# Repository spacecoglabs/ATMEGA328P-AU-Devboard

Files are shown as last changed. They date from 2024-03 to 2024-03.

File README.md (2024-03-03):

# ATMEGA328P-AU-Devboard
A simple KiCADv6 design for a ATMEGA328P-AU Development Board

## Overview 
This repository contains a simple KiCADv6 design for a ATMEGA328P-AU development board. All pins are broken out to headers for prototyping use, with a few exceptions. This design includes an external 16MHz oscillator, power indicator LED, and user controllable LED. The form factor of the board was designed to be as small as possible, without compromising usability. Power can be supplied through the screw terminal, or directly through the various 5V and GND pins.

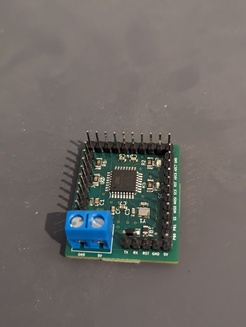
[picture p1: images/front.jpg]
front

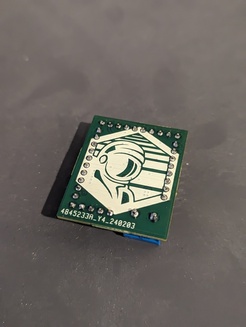
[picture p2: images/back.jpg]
back


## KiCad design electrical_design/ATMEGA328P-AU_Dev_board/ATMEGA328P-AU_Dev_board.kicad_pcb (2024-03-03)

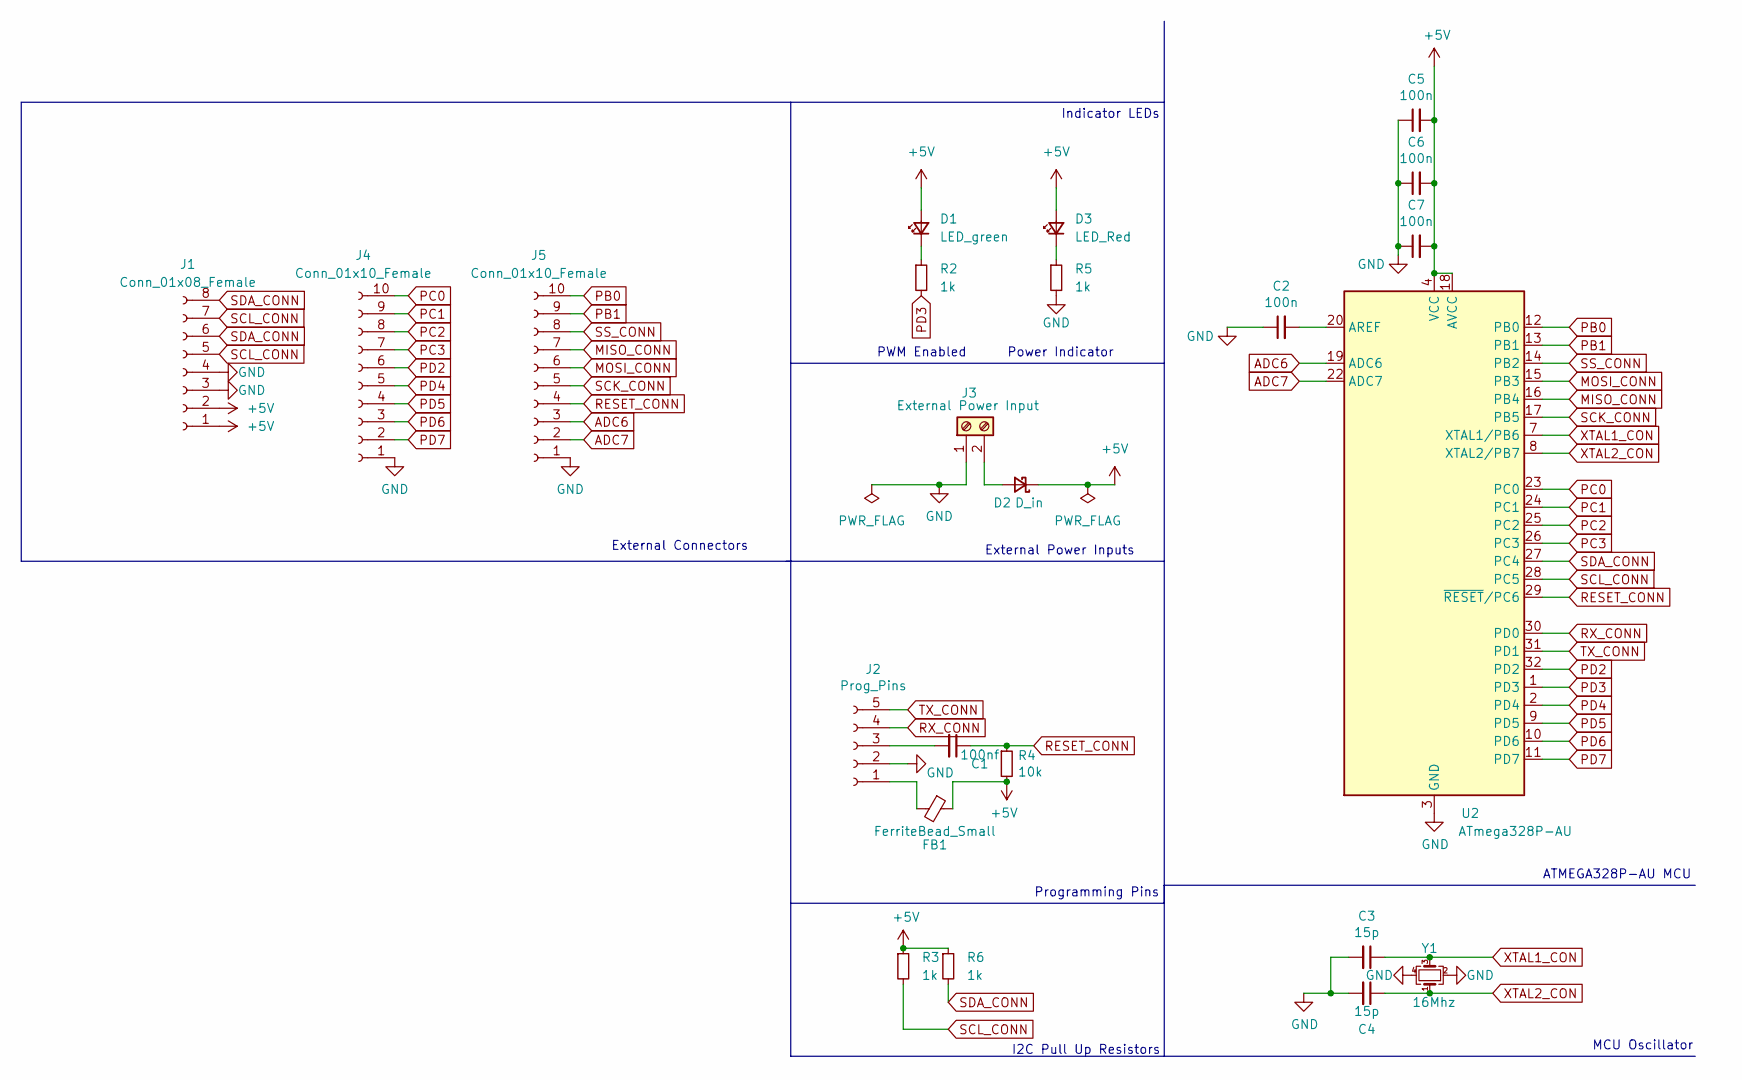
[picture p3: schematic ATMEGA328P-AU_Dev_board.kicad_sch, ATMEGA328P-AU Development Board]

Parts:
C1: 100nf; C_0603_1608Metric; LCSC C14663
C2, C5, C6, C7: 100n; C_0603_1608Metric; LCSC C14663
C3, C4: 15p; C_0603_1608Metric; LCSC C1644
D1: LED_green; LED_0805_2012Metric; LCSC C2297
D2: D_in; D_SOD-123; LCSC C8598
D3: LED_Red; LED_0603_1608Metric; LCSC C2286
FB1: FerriteBead_Small; L_0805_2012Metric; LCSC C96710
J1: Conn_01x08_Female; Conn_8
J2: Prog_Pins; Conn_5
J3: External Power Input; two_pin_screw_term
J4, J5: Conn_01x10_Female; Conn_10
R2, R3, R5, R6: 1k; R_1206_3216Metric; LCSC C4410
R4: 10k; R_0603_1608Metric; LCSC C25804
U2: ATmega328P-AU; TQFP-32_7x7mm_P0.8mm; LCSC C14877
Y1: 16Mhz; Crystal_SMD_2520-4Pin_2.5x2.0mm; LCSC C284159

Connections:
+5V: C5.2, C6.2, C7.2, D1.2 (A), D2.1 (K), D3.2 (A), FB1.1, J1.1, J1.2, R3.1, R4.2, R6.1, U2.4 (VCC), U2.6 (VCC), U2.18 (AVCC)
ADC6: J5.3, U2.19 (ADC6)
ADC7: J5.2, U2.22 (ADC7)
GND: C2.1, C3.2, C4.2, C5.1, C6.1, C7.1, J1.3, J1.4, J2.2, J3.1, J4.1, J5.1, R5.2, U2.3 (GND), U2.5 (GND), U2.21 (GND), Y1.2, Y1.4
MISO_CONN: J5.7, U2.16 (PB4)
MOSI_CONN: J5.6, U2.15 (PB3)
unnamed: C1.2, J2.3
unnamed: C2.2, U2.20 (AREF)
unnamed: D1.1 (K), R2.1
unnamed: D2.2 (A), J3.2
unnamed: D3.1 (K), R5.1
unnamed: FB1.2, J2.1
PB0: J5.10, U2.12 (PB0)
PB1: J5.9, U2.13 (PB1)
PC0: J4.10, U2.23 (PC0)
PC1: J4.9, U2.24 (PC1)
PC2: J4.8, U2.25 (PC2)
PC3: J4.7, U2.26 (PC3)
PD2: J4.6, U2.32 (PD2)
PD3: R2.2, U2.1 (PD3)
PD4: J4.5, U2.2 (PD4)
PD5: J4.4, U2.9 (PD5)
PD6: J4.3, U2.10 (PD6)
PD7: J4.2, U2.11 (PD7)
RESET_CONN: C1.1, J5.4, R4.1, U2.29 (~RESET/PC6)
RX_CONN: J2.4, U2.30 (PD0)
SCK_CONN: J5.5, U2.17 (PB5)
SCL_CONN: J1.5, J1.7, R3.2, U2.28 (PC5)
SDA_CONN: J1.6, J1.8, R6.2, U2.27 (PC4)
SS_CONN: J5.8, U2.14 (PB2)
TX_CONN: J2.5, U2.31 (PD1)
XTAL1_CON: C3.1, U2.7 (XTAL1/PB6), Y1.3
XTAL2_CON: C4.1, U2.8 (XTAL2/PB7), Y1.1

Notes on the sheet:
MCU Oscillator
PWM Enabled
ATMEGA328P-AU MCU
External Connectors
Power Indicator
External Power Inputs
Indicator LEDs
I2C Pull Up Resistors
Programming Pins

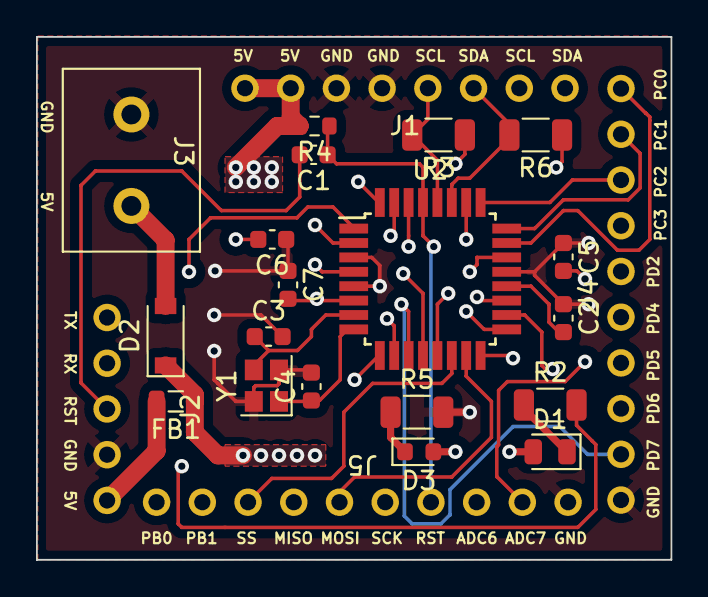
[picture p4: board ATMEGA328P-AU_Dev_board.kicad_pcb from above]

Board: 4 copper layers, 35.2 x 29.0 mm, 23 parts (0 on the bottom side), 33 nets.
